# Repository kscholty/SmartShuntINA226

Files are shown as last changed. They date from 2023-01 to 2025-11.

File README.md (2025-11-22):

## Overview
This project uses an INA226 shunt amplifier to implement some smart shunt functionality.
It sums up the charges that move through the shunt. With this information it tries to calculate the load status of an attached battery.
The INA226 should be connected to the shunt so that charges going into the battery are positive and those coming out of the battery are negtive.

The smart shunt has three main interfaces.

1) A web interface for human users. It allows setting the main parameters of the system and displays the current status of the system
2) A modbus interface that is based on a PZEM017 energy meter but enhances it with the values mentioned above
3) Victron VE.direct Text and Hex protocols in order to function as a Battery Monitor. The Hex protocol is only implemented as far as it's required for startup. Furthermore, some fields of the Text protocol are not yet filled correctly.

## Building the code yourself
The Software has been created using platformio and the Arduino environment. In order to build it you als need some libraries.
* the [INA226lib](https://github.com/peterus/INA226Lib) The latest version should work with this code.
* emelianov/modbus-esp8266
* locoduino/RingBuffer
* prampec/IotWebConf

The latter three will be automatically downloaded when using platformio.

## Required hardware

For measuring the current you need an __INA226 breakout board__ as you can acquire from 
[Amazon](https://www.amazon.de/ALAMSCN-Bi-Directional-Voltage-Current-Monitoring/dp/B09Z66QSPB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),
[Ebay](https://www.ebay.de/itm/403798012528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) or [AliExpress](https://de.aliexpress.com/item/1005001593541480.html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)

I noticed that some of the boards have a different pinout. The SDA and SDL pins are swapped in comparison to others. So please check this if you can't get a connection to the sensor.

As __miocrocontroller__ I settled for Espressif products. This code has been tested with a Wemos D1 Mini, a Wemos S2 mini and a 8266 Nodemcu. I didn't test any ESP32 WROOM boards, but they should work too. I setteled for the S2 mini due to its small footprint and powerful CPU. I got mine from [Aliexpress](https://de.aliexpress.com/item/1005004438665554.html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)

You also need a __shunt__, since the small resistor on the board (dont forget to remove it!) will not survive the high currents of a PV plant.
There are plenty of options out there. Again [Aliexpress](https://de.aliexpress.com/item/1005001678592758.html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) or [Ebay](https://www.ebay.de/sch/i.html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) are probably the best sources.
Make sure that you select a resistor appropriate for the currents you expect. I'm using a 200A/75mV shunt.

I recommend using a __buck converter__ to create 5V for feeding the MCU and the sensor from the battery. 
Make sure Battery - is connected to the GND potential of the sensor. Otherwise the voltage measurements will be invalid, since the INA226 has only one GND.
Furthermore, you should use an __isolated USB module__ to connect the D1 to the target. You can destroy your computer or Victron GSX if you connect it directly to the USB of the MCU. [I use this one](https://www.ebay.de/itm/164934927888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)

__Before you can use the sensor board you have to remove the shunt resistor soldered to that board and instead use a bigger shunt, e.g. a 100A/75mV.__
Make sure that the shunt supports the current your system produces. You can set the parameters of the shunt in the web interface.
A wide variety of shunts can be found on EBay or other platforms.

If you have a 48V System, be aware of the fact that the INA226 does only support voltages up to 36V (40V max). You need a voltage divider to make shure your sensor is not destroyed. 
The code assumes that you use a __470KOhm and a 1MOhm__ resistor, measuring across the 1MOhm towards GND. `( + --470K-- --1M -- GND )` This should work for a 16S LifePO4 battery. The smaller you choose the small resistor in comparison to the bigger one, the more accurate the measurement will be.

The configuration field `Voltage calibration factor` can be used to calibrate the voltage reading of the sensor. Set it to `1000` and then simply divide the real battery voltage by the value the sensor shows and multiply it by `1000`. 
The same can be done for the current in the field `Current calibration factor`. If you entered the shunt resistance correctly, a value close to 1000 is expected here. Mine is 1028.5.

The following image shows how to connect the parts.
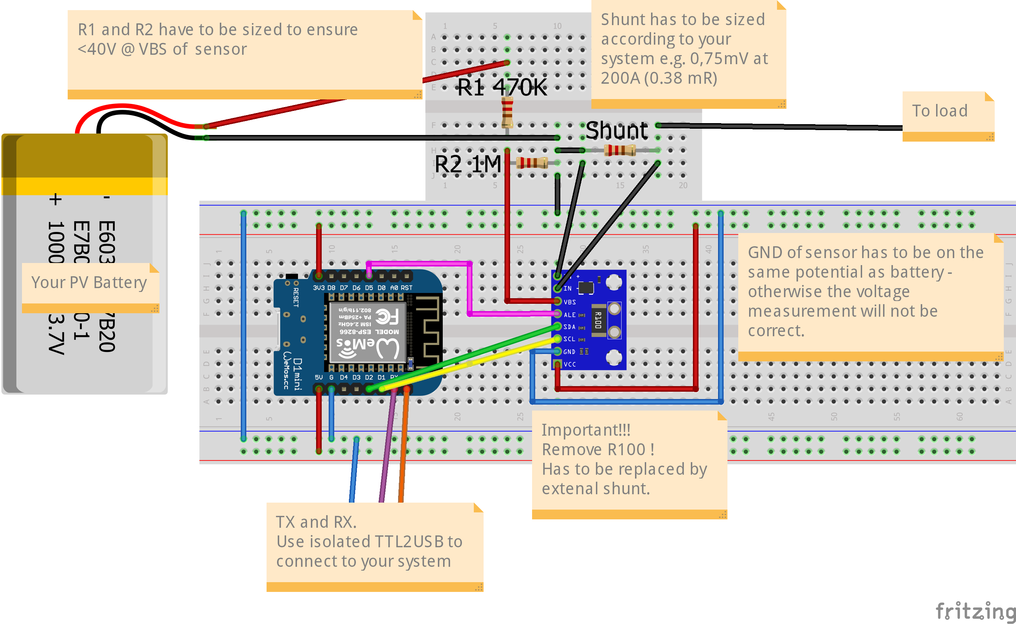
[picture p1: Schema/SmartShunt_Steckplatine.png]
Breadboard


## Interfaces:

1) Web Interface. 
    The web interface is quite self explanatory. It contains values to configure the shunt you are using. 
    Furthermore some that have been inspired by the Victron SmartShunt. 
2) Victron Text and Hex Protocols. These are decirbed on the  Victron Website and are mainly useful for connecting to Victron Cerbos or othe GX devices.
    Victron Device Type allow to declare Smart Shunt as a monitor for external load or supply: DC load, wind/water turbine, car alternator...
4)  The Modbus interface
    The Modbus interface uses 9600 Buad 8N2. The following registers are exposed
    - Holding registers (the first 4 are the ones from a PZEM-017)
    ```
        0: High Voltage alarm Threshold (not functional at the moment)
        1: Low Voltage alarm Threshold (not functional at the moment)
        2: Modbus Address
        3: Shunt Value (Refer to table below) what the values mean
        4: Identifier (This register contains the ID 0xBF39D to distinguish it from other sensors)
        5: Set SOC (Can be used to set an SOC, e.g. after startup)
    ```
    - Input Registers (again the first 8 are identical to the PZEM-017, however, here the current and power can be negative)
    ```
        0: Bus Voltage
        1: Current
        2: PowerLow (power low word)
        3: PowerHigh (power high word)
        4: EnergyLow (Energy low word)
        5: EnergyHigh (Energy high word)
        6: HighVoltageAlarm status (Is high voltage alarm set, not yet functional)
        7: LowVoltageAlarm status (Is high voltage alarm set, not yet functional)
        8: TimeToGoLow (LowWord of timeToGo in Seconds)
        9: TimeToGoHigh (HighWord of timeToGo in Seconds)
        10: SOC (Soc in %)
        11: isFull (1 if battery is detected to be full, 0 otherwise)
    ```

Shunt values for modbus, assumed is a voltage of 75mV at nominal current. 
The values are those used by PZEM-017.

```
Register Value | nominal current | Resulting resistance mR
0              |  100A           |  0.750
1              |   50A           |  1.500
2              |  200A           |  0.375
3              |  300A           |  0.250
```

When you start the sensor for the first time it will open an access point you can connect to in order to set wifi credentials and the other parameters.
After connecting to that access point, direct your browser to `http://192.168.4.1`. This will open the configuration page.
The sensor will always create that access point after startup. For how long can be configured. 

## Screenshots

## Remote console with Shunt
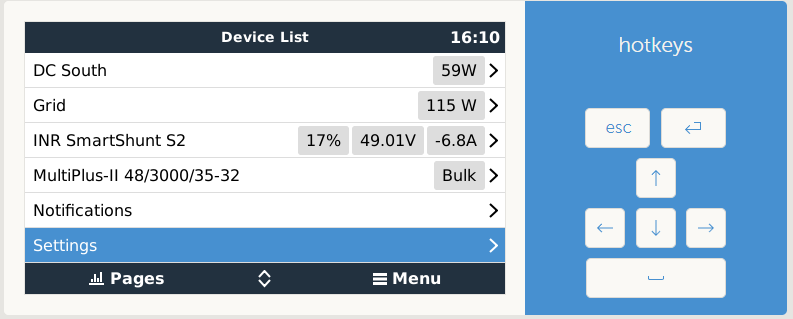
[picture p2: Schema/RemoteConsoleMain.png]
Console1


## Remote console details
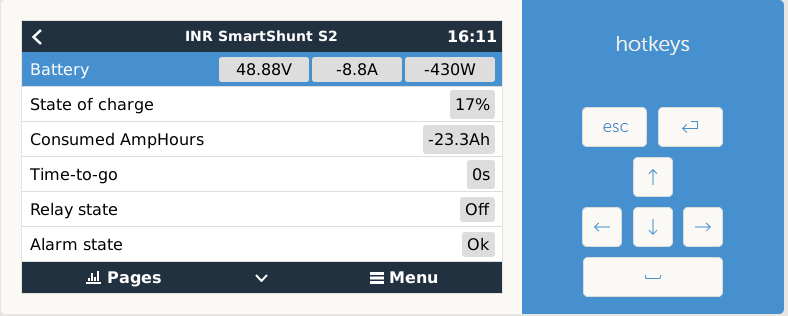
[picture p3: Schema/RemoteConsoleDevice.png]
Console2


## Remote console details for DC system
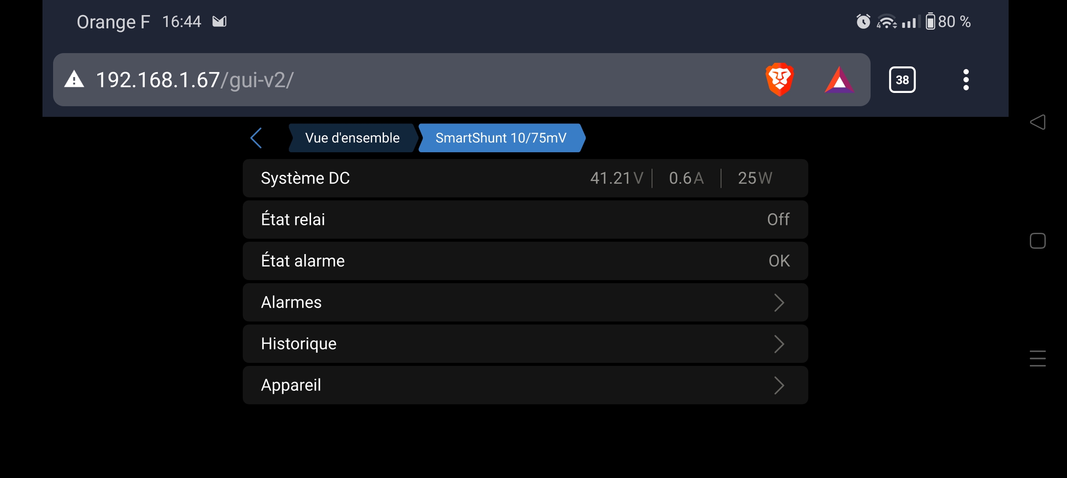
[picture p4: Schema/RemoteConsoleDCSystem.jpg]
ConsoleDC


## Real setup with SmartShunt as a DC System
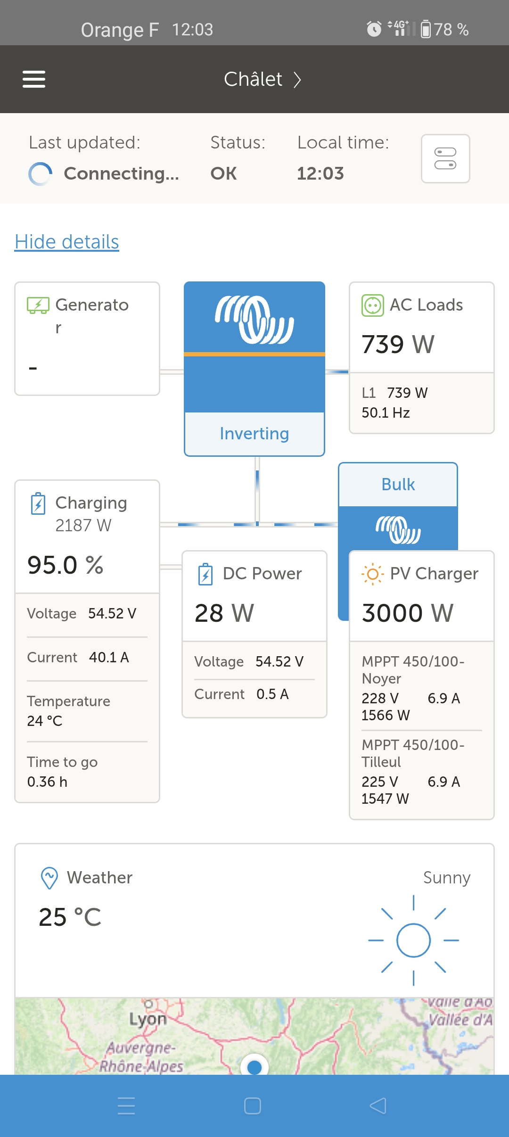
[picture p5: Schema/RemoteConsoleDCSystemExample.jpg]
ConsoleReal


## Web config
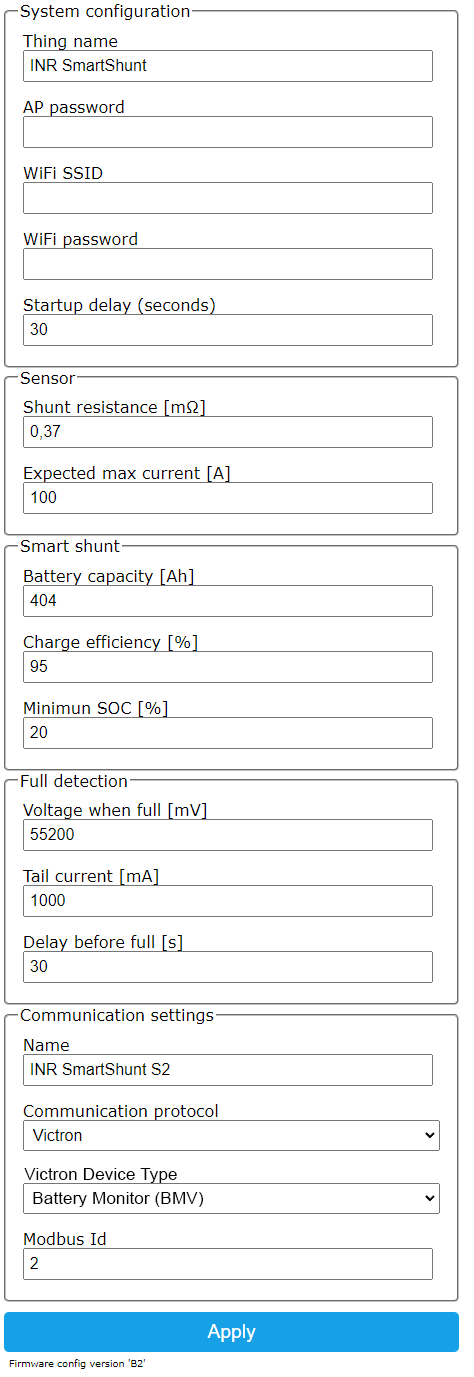
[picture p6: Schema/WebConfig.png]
Web config


## Web config for Victron Device Type
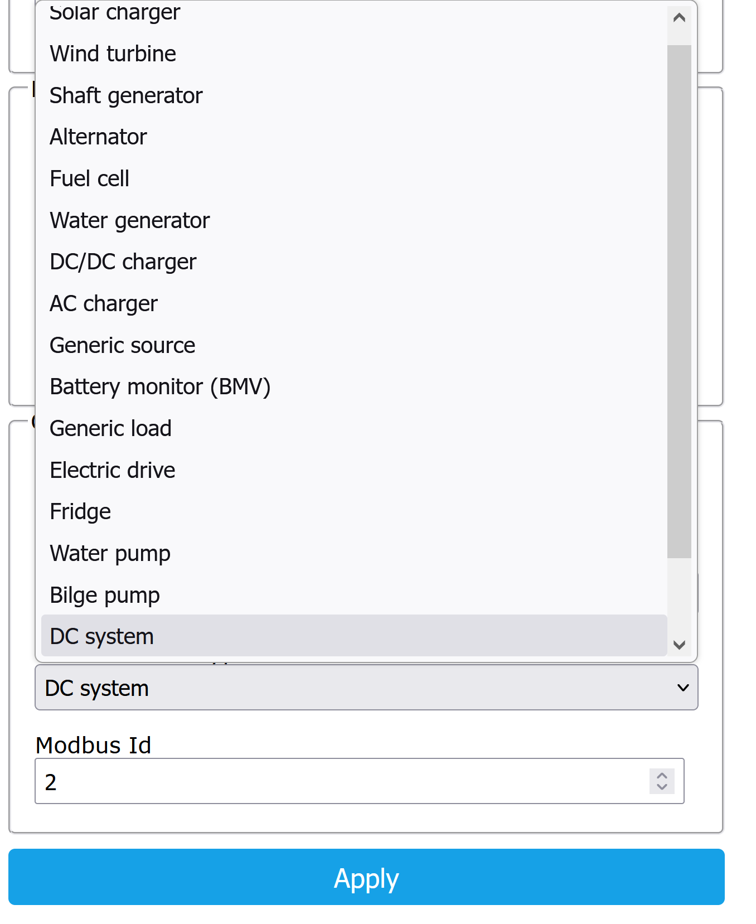
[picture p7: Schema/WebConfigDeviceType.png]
Web config DC


## Everything soldered together
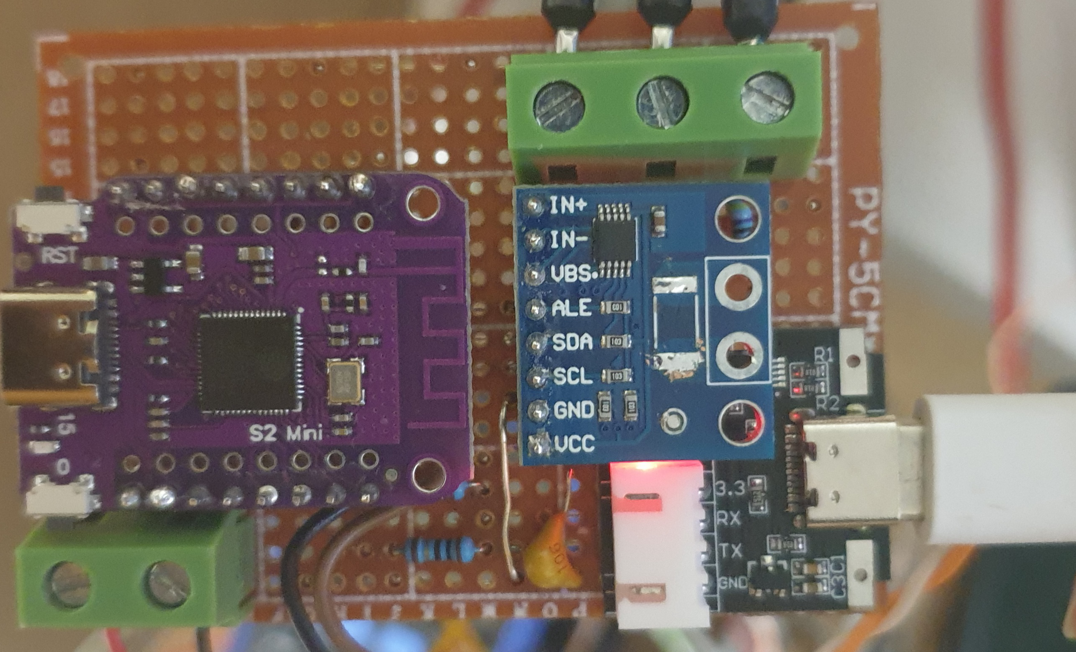
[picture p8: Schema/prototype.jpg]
Prototype


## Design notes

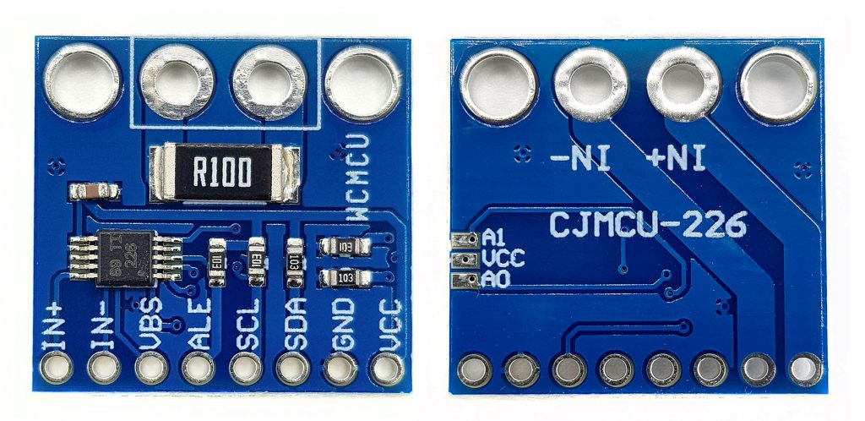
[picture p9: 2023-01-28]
Schema/INA226_Modul-1024x498.jpg

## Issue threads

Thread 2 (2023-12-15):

Platformio Environment to compile the code

itgenmar, 2023-12-15:
Could you help me to setup the environment to be able to compile ?

I am getting this error :

Processing release_nodemcu (board: nodemcuv2; framework: arduino; platform: espressif8266)
----------------------------------------------------------------------------------------------------------------------------------------------------------------------------------------------------------------Verbose mode can be enabled via `-v, --verbose` option
CONFIGURATION: https://docs.platformio.org/page/boards/espressif8266/nodemcuv2.html
PLATFORM: Espressif 8266 (4.2.1) > NodeMCU 1.0 (ESP-12E Module)
HARDWARE: ESP8266 80MHz, 80KB RAM, 4MB Flash
PACKAGES:
 - framework-arduinoespressif8266 @ 3.30102.0 (3.1.2)
 - tool-esptool @ 1.413.0 (4.13)
 - tool-esptoolpy @ 1.30000.201119 (3.0.0)
 - toolchain-xtensa @ 2.100300.220621 (10.3.0)
LDF: Library Dependency Finder -> https://bit.ly/configure-pio-ldf
LDF Modes: Finder ~ deep, Compatibility ~ soft
Found 42 compatible libraries
Scanning dependencies...
Dependency Graph
|-- INA226Lib @ 1.1.3
|-- modbus-esp8266 @ 4.1.0
|-- RingBuffer @ 1.0.4
|-- IotWebConf @ 3.2.1
|-- Wire @ 1.0
|-- ArduinoOTA @ 1.0
|-- DNSServer @ 1.1.1
|-- ESP8266WiFi @ 1.0
Building in debug mode
Compiling .pio\build\release_nodemcu\src\sensorHandling.cpp.o
Archiving .pio\build\release_nodemcu\lib1d3\libESP8266WiFi.a
Archiving .pio\build\release_nodemcu\libc99\libESP8266mDNS.a
Archiving .pio\build\release_nodemcu\libf47\libDNSServer.a
Compiling .pio\build\release_nodemcu\libbaf\ESP8266WebServer\detail\mimetable.cpp.o
Compiling .pio\build\release_nodemcu\lib84f\IotWebConf\IotWebConf.cpp.o
Compiling .pio\build\release_nodemcu\lib84f\IotWebConf\IotWebConfMultipleWifi.cpp.o
Compiling .pio\build\release_nodemcu\lib84f\IotWebConf\IotWebConfOptionalGroup.cpp.o
Compiling .pio\build\release_nodemcu\lib84f\IotWebConf\IotWebConfParameter.cpp.o
Compiling .pio\build\release_nodemcu\lib813\ArduinoOTA\ArduinoOTA.cpp.o
Archiving .pio\build\release_nodemcu\libFrameworkArduinoVariant.a
Compiling .pio\build\release_nodemcu\FrameworkArduino\Crypto.cpp.o
Compiling .pio\build\release_nodemcu\FrameworkArduino\Esp-frag.cpp.o
Compiling .pio\build\release_nodemcu\FrameworkArduino\Esp-version.cpp.o
Compiling .pio\build\release_nodemcu\FrameworkArduino\Esp.cpp.o
Compiling .pio\build\release_nodemcu\FrameworkArduino\FS.cpp.o
Archiving .pio\build\release_nodemcu\libbaf\libESP8266WebServer.a
Compiling .pio\build\release_nodemcu\FrameworkArduino\FSnoop.cpp.o
src\sensorHandling.cpp: In function 'void sensorLoop()':
src\sensorHandling.cpp:330:32: error: 'class INA226' has no member named 'isConversionReady'
  330 |     while (alertCounter && ina.isConversionReady()) {
      |                                ^~~~~~~~~~~~~~~~~
*** [.pio\build\release_nodemcu\src\sensorHandling.cpp.o] Error 1
========================================================================================== [FAILED] Took 4.68 seconds ==========================================================================================
Environment      Status    Duration
---------------  --------  ------------
release_nodemcu  FAILED    00:00:04.684
==================================================================================== 1 failed, 0 succeeded in 00:00:04.684 ====================================================================================

 *  The terminal process "C:\Users\itgenmar\.platformio\penv\Scripts\platformio.exe 'debug'" terminated with exit code: 1.
 *  Terminal will be reused by tasks, press any key to close it.

**And this is my platformio.ini**

; PlatformIO Project Configuration File
;
;   Build options: build flags, source filter
;   Upload options: custom upload port, speed and extra flags
;   Library options: dependencies, extra library storages
;   Advanced options: extra scripting
;
; Please visit documentation for the other options and examples
; https://docs.platformio.org/page/projectconf.html

[platformio]
default_envs = release_nodemcu

[env]
framework = arduino
lib_ldf_mode = deep
lib_deps =
	emelianov/modbus-esp8266
	locoduino/RingBuffer
	prampec/IotWebConf
	peterus/INA226Lib@^1.1.3
monitor_speed = 19200
monitor_port = COM4
monitor_filters = esp8266_exception_decoder
platform = espressif8266
board_build.partitions = min_spiffs.csv
upload_protocol = esptool
build_flags = -DIOTWEBCONF_DEBUG_DISABLED -O3

[env:release_nodemcu]
board = nodemcuv2
build_type = release
upload_port = COM7
lib_deps =
	peterus/INA226Lib@^1.1.3
	emelianov/modbus-esp8266@^4.1.0
	locoduino/RingBuffer@^1.0.4
	prampec/IotWebConf@^3.2.1

[env:release_ota_nodemcu]
board = nodemcuv2
build_type = release
upload_port = 192.168.100.182
upload_protocol = espota
lib_deps =
	peterus/INA226Lib@^1.1.3
	emelianov/modbus-esp8266@^4.1.0
	locoduino/RingBuffer@^1.0.4
	prampec/IotWebConf@^3.2.1

[env:release_d1]
board = d1_mini
build_type = release
upload_port = COM7
lib_deps =
	peterus/INA226Lib@^1.1.3
	emelianov/modbus-esp8266@^4.1.0
	locoduino/RingBuffer@^1.0.4
	prampec/IotWebConf@^3.2.1

[env:release_d1_ota]
board = d1_mini
build_type = release
upload_port = 192.168.100.178
upload_protocol = espota
lib_deps =
	peterus/INA226Lib@^1.1.3
	emelianov/modbus-esp8266@^4.1.0
	locoduino/RingBuffer@^1.0.4
	prampec/IotWebConf@^3.2.1

[env:release_s2]
platform = espressif32
board = lolin_s2_mini
build_type = release
build_flags = -DIOTWEBCONF_DEBUG_DISABLED -O3
monitor_speed = 115200
lib_deps =
	peterus/INA226Lib@^1.1.3
	emelianov/modbus-esp8266@^4.1.0
	locoduino/RingBuffer@^1.0.4
	prampec/IotWebConf@^3.2.1

[env:release_s2_ota]
platform = espressif32
board = lolin_s2_mini
build_type = release
upload_port = 192.168.100.198
upload_protocol = espota
build_flags = -DIOTWEBCONF_DEBUG_DISABLED -O3
lib_deps =
	peterus/INA226Lib@^1.1.3
	emelianov/modbus-esp8266@^4.1.0
	locoduino/RingBuffer@^1.0.4
	prampec/IotWebConf@^3.2.1

kscholty, 2023-12-15:
You are probably using the wrong INA226 lib. V1.1.3 is too old. You should use the head code in peter's repository https://github.com/peterus/INA226Lib
You can check it out into the lib subfolder in the project or somewhere else where it will be found.
You sould remove the dependency in the platformio.ini to the 1.1.3 version. This one will not work.

itgenmar, 2023-12-18:
Thank you very much. I have managed to create a profile for Esp32wroom. Now
I am waiting for the ina226 from China.

thank you again

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

itgenmar, 2024-01-08:
Happy New Year,

I got the S2 mini [https://www.studiopieters.nl/esp32-s2/](https://www.studiopieters.nl/esp32-s2/) but i have no serial debugger on USB and I can't find the serial pins on it? Could you point me in the right direction ?

Thank you

itgenmar, 2024-01-08:
39 tx 40 rx

kscholty, 2024-01-08:
> 39 tx 40 rx
That's not correct.
The pins are `TX=39` and `RX=37`
This is made so that the pinout is identical to a D1 mini board.

Closed 2024-01-08.

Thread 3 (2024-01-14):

Smart shunt appears for a sec and disappears from Venus os, every 5 to 10 sec!

itgenmar, 2024-01-14:
I have this issue with the shunt appearing for 1 sec and disappearing for 10 sec.

https://github.com/kscholty/SmartShuntINA226/assets/31439546/b3f890b6-dac6-4a6c-a025-d1614553fdf7

Tried with different serial device and s2 mini.

Any help?

kscholty, 2024-01-20:
The reason is probably a loss of connection. This can be caused by different things

1) The shunt crashes.
     Do you have a stable connection to the shunt via WLAN? If it's unstable, please check the power supply. This is often a reason
     for random behaviour.
2) The communictalion line is instable.
3) The serial starter is confused.

If you have other devices connected via USB please disconnect them and reboot the GX  device, just to be sure.
If you have access to the console, please post the result of

ls /service

and the file

`/data/log/vedirect.ttyUSBX/current`
where "X" should be the USB device number (1, 2, 3 ...) the smart shunt is connected to.
This migt help.
You can also try a

`tail -f /data/log/vedirect.ttyUSBX/current`

To watch what's happening.

To check what the serial starter is doing, please check the file

`/data/log/serial-starter/current`

Hard to diagnose from remote

Closed 2024-02-05.

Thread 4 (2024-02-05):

Saving History

itgenmar, 2024-02-05:
Each time when the esp32 powers off the history is lost. Is there a way to implement saving the data?

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

itgenmar, 2024-02-05:
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

mrpeter322, 2024-06-23:
You need to save data into persistant memory as basic saving into variable (etc.) is power dependent. Please see docs for your main module and what options you have. If none just buy the external microsd slot with some microsd card or any other memory module which will be used for storing data. But focus on frequently accessing this data as measuirng writing and reading this data will be very frequent job. So maybe basic sd card option will be no go for long run. Please make some research.

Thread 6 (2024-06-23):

Options for smaller batteries

mrpeter322, 2024-06-23:
Hi. Nust wondering if the R has any other meaning as lowering the initial 16s lifepo4 voltage down to around 38V. As from my understanding you dont need Rs while using 12 or 24V (4 or 16S lifepo4) systems as this voltage is within range. Right? Can this be exluded for this systems?

If yes, are you able to edit the docs or just add some node under schematic so that other dont do this for smaller system? As lowering voltage for 12V system mean going down to around 6V in this case.

kscholty, 2024-06-23:
You are absolutely right. You need it only for systems that exceed 36V. This is why the documentation states:

_"If you have a 48V System, be aware of the fact that the INA226 does only support voltages up to 36V (40V max). You need a voltage divider to make shure your sensor is not destroyed."_

mrpeter322, 2024-06-23:
Thanks for confirmation. Enjoy!

Closed 2024-06-23.

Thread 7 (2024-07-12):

Does not compile Platformio

BisSpaeterDannnoch, 2024-07-12:
Hi, what a nice project.

I have problemes compiling the code. May I please ask you to verify if it does in your enviroment (and me being dump)?
Maybe an update gone wild after your last release...

In case in does, may ask you to upload a WemosD1 .bin file, so that I can go on with my project, until i sort out what's wrong with my enviroment.

Thank you very much and have a good time - Sven

Processing release_d1 (board: d1_mini; framework: arduino; platform: espressif8266)
---------------------------------------------------------------------------------------------------------------------------------------------------------------
Verbose mode can be enabled via `-v, --verbose` option
CONFIGURATION: https://docs.platformio.org/page/boards/espressif8266/d1_mini.html
PLATFORM: Espressif 8266 (4.2.1) > WeMos D1 R2 and mini
HARDWARE: ESP8266 80MHz, 80KB RAM, 4MB Flash
PACKAGES:
 - framework-arduinoespressif8266 @ 3.30102.0 (3.1.2)
 - tool-esptool @ 1.413.0 (4.13)
 - tool-esptoolpy @ 1.30000.201119 (3.0.0)
 - toolchain-xtensa @ 2.100300.220621 (10.3.0)
LDF: Library Dependency Finder -> https://bit.ly/configure-pio-ldf
LDF Modes: Finder ~ deep+, Compatibility ~ soft
Found 41 compatible libraries
Scanning dependencies...
Dependency Graph
|-- modbus-esp8266 @ 4.1.0
|-- INA226 @ 0.6.0
|-- Wire @ 1.0
|-- IotWebConf @ 3.2.1
|-- ESP8266SdFat @ 2.1.1
|-- ArduinoOTA @ 1.0
|-- ESP8266WiFi @ 1.0
|-- ESP8266HTTPUpdateServer @ 1.0
|-- ESP8266WebServer @ 1.0
|-- DNSServer @ 1.1.1
Building in release mode
Compiling .pio\build\release_d1\src\main.cpp.o
Compiling .pio\build\release_d1\src\modbusHandling.cpp.o
Compiling .pio\build\release_d1\src\sensorHandling.cpp.o
Compiling .pio\build\release_d1\src\statusHandling.cpp.o
src\sensorHandling.cpp:37:23: error: no matching function for call to 'INA226::INA226(TwoWire&)'
   37 | static INA226 ina(Wire);
      |                       ^
In file included from src\sensorHandling.cpp:4:
.pio\libdeps\release_d1\INA226/INA226.h:79:12: note: candidate: 'INA226::INA226(uint8_t, TwoWire*)'
   79 |   explicit INA226(const uint8_t address, TwoWire *wire = &Wire);
      |            ^~~~~~
.pio\libdeps\release_d1\INA226/INA226.h:79:33: note:   no known conversion for argument 1 from 'TwoWire' to 'uint8_t' {aka 'unsigned char'}
   79 |   explicit INA226(const uint8_t address, TwoWire *wire = &Wire);
      |                   ~~~~~~~~~~~~~~^~~~~~~
.pio\libdeps\release_d1\INA226/INA226.h:75:7: note: candidate: 'constexpr INA226::INA226(const INA226&)'
   75 | class INA226
      |       ^~~~~~
.pio\libdeps\release_d1\INA226/INA226.h:75:7: note:   no known conversion for argument 1 from 'TwoWire' to 'const INA226&'
.pio\libdeps\release_d1\INA226/INA226.h:75:7: note: candidate: 'constexpr INA226::INA226(INA226&&)'
.pio\libdeps\release_d1\INA226/INA226.h:75:7: note:   no known conversion for argument 1 from 'TwoWire' to 'INA226&&'
src\statusHandling.cpp: In member function 'void BatteryStatus::updateConsumption(float, float, uint16_t)':
src\statusHandling.cpp:60:27: error: 'class RingBuf<float, 60>' has no member named 'isFull'
   60 |         if (currentValues.isFull()) {
      |                           ^~~~~~
src\statusHandling.cpp:62:25: error: 'class RingBuf<float, 60>' has no member named 'pop'
   62 |           currentValues.pop(oldVal);
      |                         ^~~
src\statusHandling.cpp:65:23: error: 'class RingBuf<float, 60>' has no member named 'push'
   65 |         currentValues.push(current);
      |                       ^~~~
src\statusHandling.cpp:70:22: error: 'class RingBuf<float, 60>' has no member named 'isEmpty'
   70 |     if(currentValues.isEmpty()) {
      |                      ^~~~~~~

kscholty, 2024-07-12:
Du hast die falsche  Version der INA226 Lib. Du musst die von mir hier nehmen, wie im Readme beschrieben.
Ich habe aber mal aktuelle Binaries hochgeladen. Das Release v1.1.0 enthält die aktuellste Version.
Viel Spaß.

BisSpaeterDannnoch, 2024-07-12:
Du bist so gut. Vielen Dank und eine gute Zeit!

kscholty ***@***.***> schrieb am Fr., 12. Juli 2024, 20:42:

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

BisSpaeterDannnoch, 2024-07-13:
danke noch einmal.  Es lebt jetzt auf einem  D1 mini lite, hängt in meinem Netz und und belohnt mich alle 5 sec mit einem led-flash :) Nun warte ich auf die restlichen Bauteile von Ali.
Gute Zeit.

Closed 2024-07-12.

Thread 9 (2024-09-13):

Some fields of the Text protocol are not yet filled correctly

oa4ajp, 2024-09-13:
Hello,

**I have read this on the project readme:**
Victron VE.direct Text and Hex protocols in order to function as a Battery Monitor. The Hex protocol is only implemented as far as it's required for startup. Furthermore, some fields of the **Text protocol are not yet filled correctly**.

Does it mean that the smart shunt INA226 has limitations or partial functionality with Venus OS?

I'm asking before start building your design.

Regards
Alfredo Mendiola

kscholty, 2024-09-13:
The statistics are not complete and they are not persistent.
It doesn't have any relay support and you can't configure any alarms.
That's the only restrictions I remember from the top of my head.

Closed 2024-09-13.

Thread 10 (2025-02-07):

INA228 for 48V, plus better accuracy?

ppanag, 2025-02-07:
Hi.

Can I use this INA228 board for 48V battery ? It also has 20 bit accuracy..

https://www.aliexpress.com/item/1005007494781503.html

kscholty, 2025-02-07:
Looks as if you could use it.
Since I didn't know the chip I can't tell you what would have to be modified in the code, but if the command set is identical it could work out of the box.
If you try it, please let me know the results.

Closed 2025-02-07.

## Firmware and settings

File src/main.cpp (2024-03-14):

/*
    INA226 Bi-directional Current/Power Monitor. Simple Example.
    Read more:
   http://www.jarzebski.pl/arduino/czujniki-i-sensory/cyfrowy-czujnik-pradu-mocy-ina226.html
    GIT: https://github.com/jarzebski/Arduino-INA226
    Web: http://www.jarzebski.pl
    (c) 2014 by Korneliusz Jarzebski
*/
#include <Arduino.h>
#include <Wire.h>
#include <INA226.h>

#include "common.h"
#include "sensorHandling.h"
#include "webHandling.h"
#include "modbusHandling.h"
#include "victronHandling.h"


void setup() {
#if ARDUINO_USB_CDC_ON_BOOT
    SERIAL_VICTRON.begin(19200, SERIAL_8N1, RX, TX);
    // there seems to be a bug in the Arduine core that 
    // prevents RX from working. The next line fixes that....
    SERIAL_VICTRON.setPins(RX, TX, -1, -1);
    SERIAL_DBG.begin(115200);
#else
    SERIAL_DBG.begin(19200);
#endif
    
    wifiSetup();

#if (SOC_UART_NUM > 1)
    SERIAL_MODBUS.begin(9600, SERIAL_8N2);
#endif

    sensorInit();
    modbusInit();
    victronInit();
}

void loop() {

    wifiLoop();
    if (gParamsChanged) {
        modbusInit();
        victronInit();
    }
    sensorLoop();
    modbusLoop();
    victronLoop();
    gParamsChanged = false;

}

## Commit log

2022-12-30 Modbus is functional and parameters can be written Updated parameters are handled glidingAverage current is now correct.
    [main.cpp]
2023-01-06 Updated handlingof sensor failure
    [main.cpp]
2023-01-19 More Modbus registers, Runtime values (Currently only SOC) can be set from Web-GUI
    [SmartShunt.fzz]
2023-01-28 Added Schema
    [SmartShunt.fzz]
2023-01-29 Allow usage of ESP S2 Mini instead of D1 Mini Enhanced schematics
    [SmartShunt.fzz]
2023-02-02 More documentation Make sure statistrics update and victron update are in sync Schema updated
    [SmartShunt.fzz]
2023-02-03 Updated Reame.md
    [SmartShunt.fzz]
2023-02-11 Fixed Min and Max voltage in stats storing statistics in RTC memory to survive resets Calibration factors fro vopltage an current
2024-03-14 Calibration values can now be set from the UI. Firmware updates from the webui Better handling of "full" detection
2025-11-20 Updated ReadMe for new Device Type
